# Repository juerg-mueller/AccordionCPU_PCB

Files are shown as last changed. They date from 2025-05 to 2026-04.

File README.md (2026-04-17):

# AccordionCPU_PCB

PCB ist mit KiCad gezeichnet worden. Zur Programmierung der Firmware (firmware.bin) braucht man folgende Tools:

https://www.espressif.com/en/support/download/other-tools

[AkkordeonCPU.pdf](https://github.com/user-attachments/files/20022553/AkkordeonCPU.pdf)

Akkordeon

Alle zur Bestückung notwendigen Teile können bei Reichelt.de bestellt werden:

Kondenstor 100nF: KERKO 100N (0.03 €)

Widerstände 33kOhm: 1/4W 33k (0.11 €)

Widerstände 220Ohm: 1/4W 220 (0.11 €)

Widerstand 1kOhm: 1/4W 1K (0.11 €)

IC-Sockel DIL 14: GS 14P (0.27 €)

IC 74HC00: SN 74HC00 (0.46 €)

Display: DEBO OLED2 0.96 (6 €)

ESP32-S3-DevKitC: ESP32-S3-DevKitC-1-N8R8 (ca. 16 €) / auch bei mouser.de: 356-EP32S3DVKTC1N8R8

Wannenstecker 20-polig gewinkelt: WSL 20W (0.31 €)

Pfostenbuchse 20-polig: PFL 20 (0.30 €)

Flachbandkabel 20-polig: AWG 28-20G 3M (3.20 €)

Wannenstecker 6-polig: WSL 6G (0.17 €)

Pfostenbuchse 6-polig: PFL 6 (0.24 €)

Anschlussklemme: AKL 101-02 (0.25 €)

wahl Esp32

flash-esp32

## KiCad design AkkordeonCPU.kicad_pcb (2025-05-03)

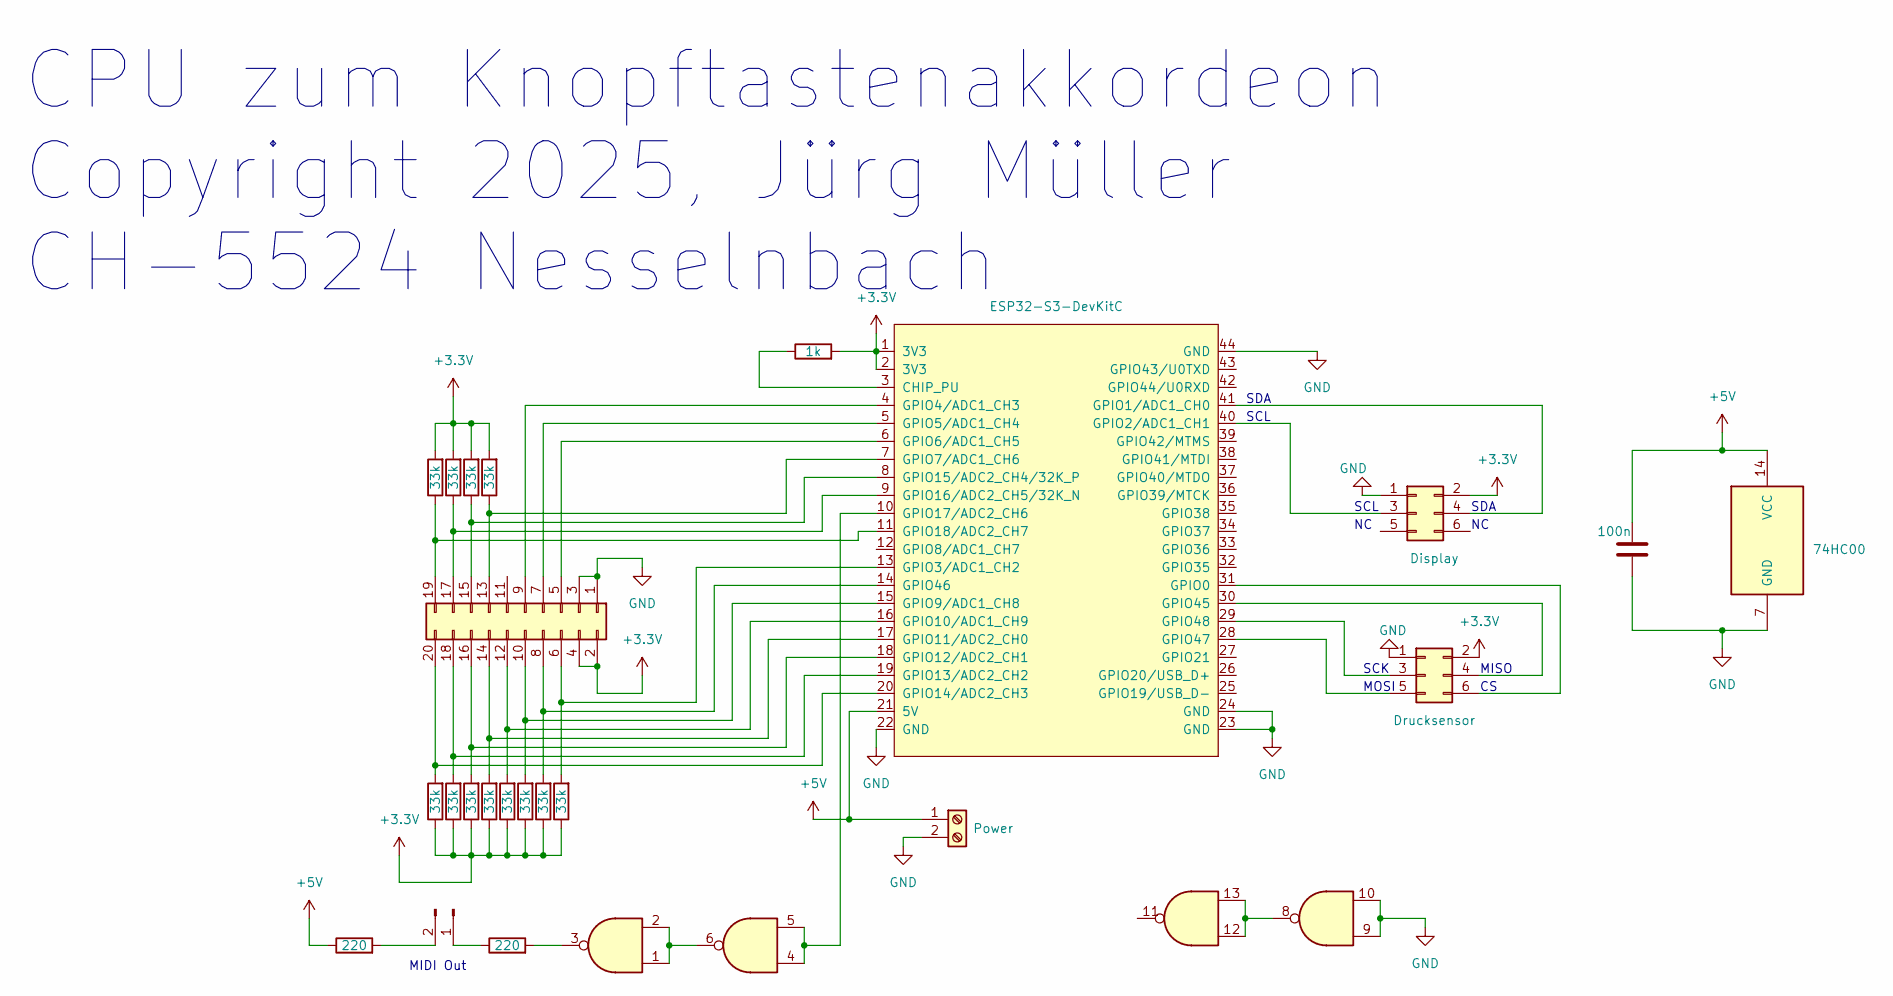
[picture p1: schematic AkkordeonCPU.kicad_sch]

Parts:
C1: 100n; C_Disc_D5.0mm_W2.5mm_P5.00mm
J1: MIDI Out; PinHeader_1x02_P2.54mm_Vertical
J2: Conn_02x10_Odd_Even; PinHeader_2x10_P2.54mm_Vertical
J3: Display; Box_2x3
J4: Drucksensor; Box_2x3
J8: Power; TerminalBlock_bornier-2_P5.08mm
R1, R15: 220; R_Axial_DIN0207_L6.3mm_D2.5mm_P10.16mm_Horizontal
R2, R3, R4, R5, R6, R7, R8, R9, R10, R11, R12, R13: 33k; R_Axial_DIN0207_L6.3mm_D2.5mm_P10.16mm_Horizontal
R14: 1k; R_Axial_DIN0207_L6.3mm_D2.5mm_P10.16mm_Horizontal
U1: 74HC00; DIP-14_W7.62mm_LongPads
U2: ESP32-S3-DevKitC

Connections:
+5V: C1.2, J8.1, R1.1, U1.14 (VCC), U2.21 (5V)
GND: C1.1, J2.1, J2.3, J3.1, J4.1, J8.2, U1.7 (GND), U1.9, U1.10, U2.22 (GND), U2.23 (GND), U2.24 (GND), U2.44 (GND)
unnamed: J1.1, R15.1
unnamed: J1.2, R1.2
unnamed: J2.5, U2.6 (GPIO6/ADC1_CH5)
unnamed: J2.6, R13.2, U2.13 (GPIO3/ADC1_CH2)
unnamed: J2.7, U2.5 (GPIO5/ADC1_CH4)
unnamed: J2.8, R12.2, U2.14 (GPIO46)
unnamed: J2.9, U2.4 (GPIO4/ADC1_CH3)
unnamed: J2.10, R11.2, U2.15 (GPIO9/ADC1_CH8)
unnamed: J2.12, R10.2, U2.16 (GPIO10/ADC1_CH9)
unnamed: J2.13, R8.1, U2.7 (GPIO7/ADC1_CH6)
unnamed: J2.14, R9.2, U2.17 (GPIO11/ADC2_CH0)
unnamed: J2.15, R6.1, U2.8 (GPIO15/ADC2_CH4/32K_P)
unnamed: J2.16, R7.2, U2.18 (GPIO12/ADC2_CH1)
unnamed: J2.17, R4.1, U2.9 (GPIO16/ADC2_CH5/32K_N)
unnamed: J2.18, R5.2, U2.19 (GPIO13/ADC2_CH2)
unnamed: J2.19, R2.1, U2.11 (GPIO18/ADC2_CH7)
unnamed: J2.20, R3.2, U2.20 (GPIO14/ADC2_CH3)
unnamed: J3.3, U2.40 (GPIO2/ADC1_CH1)
unnamed: J3.4, U2.41 (GPIO1/ADC1_CH0)
unnamed: J4.3, U2.29 (GPIO48)
unnamed: J4.4, U2.30 (GPIO45)
unnamed: J4.5, U2.28 (GPIO47)
unnamed: J4.6, U2.31 (GPIO0)
unnamed: R14.1, U2.3 (CHIP_PU)
unnamed: R15.2, U1.3
unnamed: U1.1, U1.2, U1.6
unnamed: U1.4, U1.5, U2.10 (GPIO17/ADC2_CH6)
unnamed: U1.8, U1.12, U1.13

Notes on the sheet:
SCK
MISO
MOSI
MIDI Out
SCL
CPU zum Knopftastenakkordeon Copyright 2025, Jürg Müller CH-5524 Nesselnbach
SDA
SDA

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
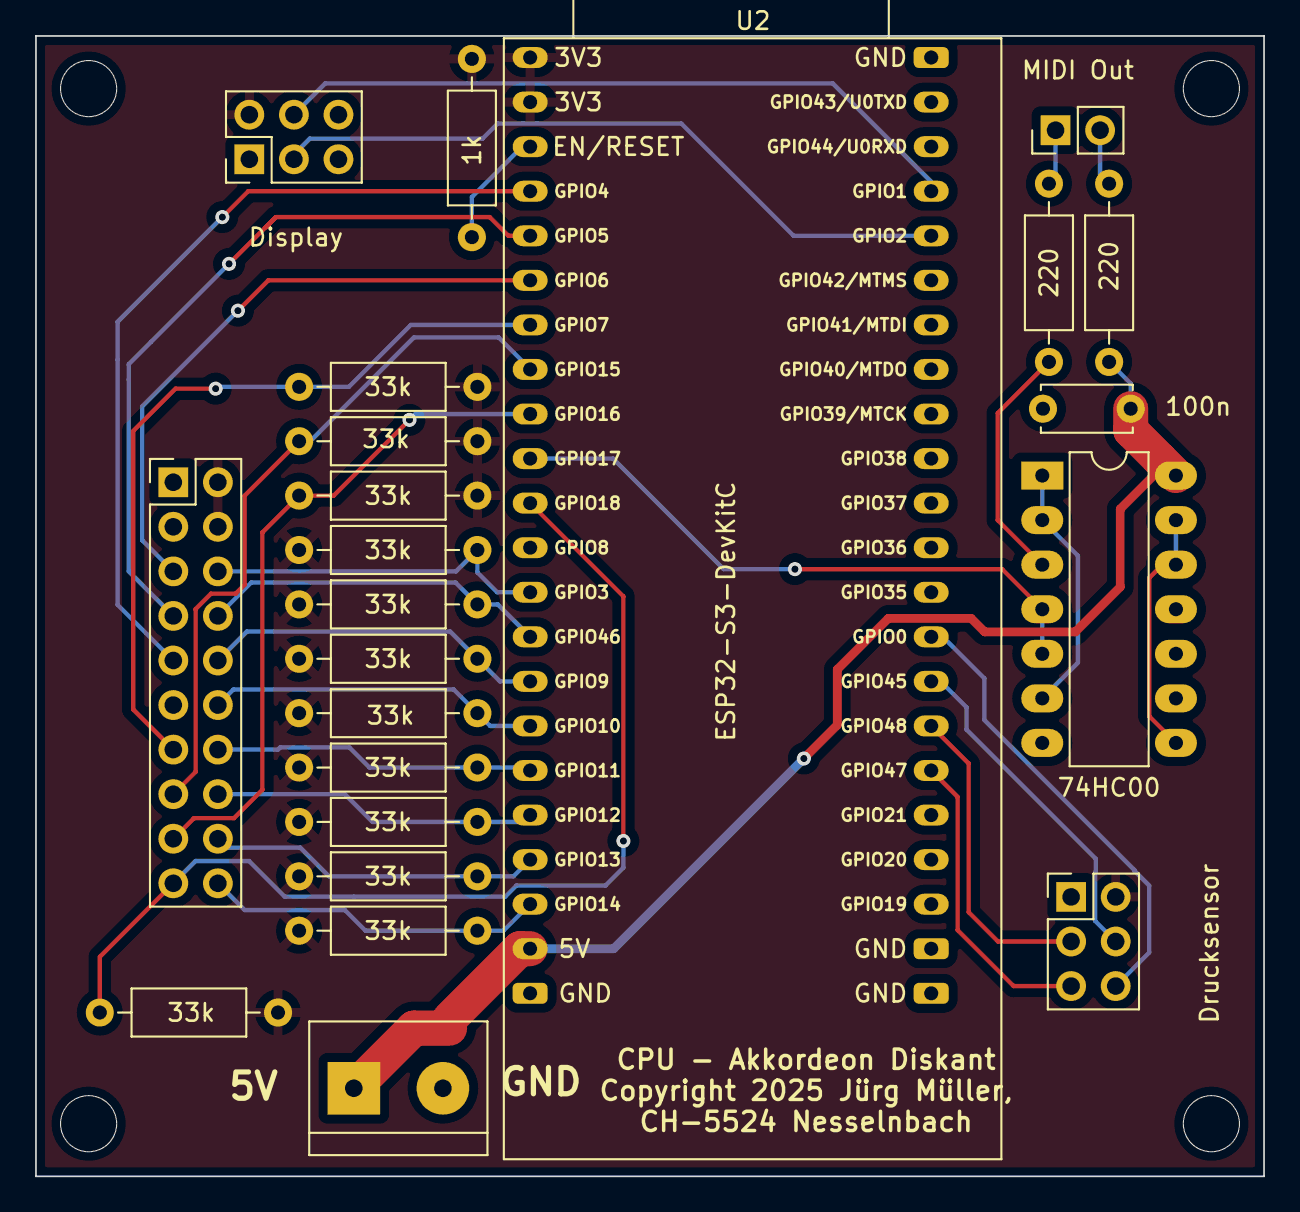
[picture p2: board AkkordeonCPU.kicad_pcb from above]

Board: 2 copper layers, 70.0 x 65.0 mm, 27 parts (0 on the bottom side), 31 nets.

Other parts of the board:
REF2, REF2#2, REF2#3, REF2#4: MountingHole_3.2mm_M3_ISO7380
